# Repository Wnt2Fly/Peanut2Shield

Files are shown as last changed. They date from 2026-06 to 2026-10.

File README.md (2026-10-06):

# Peanut2Shield — TiVo Remote BLE HID Translator

**Firmware v1.21** — see [CHANGELOG.md](CHANGELOG.md)

An ESP32-S3 firmware that bridges a **TiVo Stream 4K remote** to an **Nvidia Shield TV** over Bluetooth LE — no WiFi, no app, no cloud.

<a href="https://www.buymeacoffee.com/wnt2fly" target="_blank">Buy Me A Coffee</a>

    

**Topics:** `esp32` · `esp32-s3` · `ble` · `bluetooth-low-energy` · `hid` · `nimble` · `nvidia-shield` · `android-tv` · `tivo` · `tivo-remote` · `platformio` · `waveshare`

---

## What it does

```
TiVo Remote  ──BLE HID──►  ESP32-S3  ──BLE HID──►  Nvidia Shield TV
              (Central)   Translator   (Peripheral)
```

The ESP32-S3 simultaneously acts as:

- **BLE Central** — connects to the TiVo remote as a HID host and receives button reports
- **BLE Peripheral** — advertises as a HID keyboard + consumer control device to the Shield

When a button is pressed on the TiVo remote, the firmware translates it (if needed) and forwards it to the Shield in real time.  Shield and TiVo bond addresses are stored in **NVS**; BLE keys persist across reboot when NimBLE bonding is enabled. After a normal reset or power cycle, the bridge **reconnects to both devices automatically** — Shield first (while advertising), then TiVo — and returns to **steady green** when both links are up.

**Updating firmware:** easiest is the [prebuilt file from your browser](#flash-from-your-browser-no-install) — no software to install. Developers can use [PlatformIO](#building-from-source-platformio) (`pio run --target upload`). The first boot after flashing a **new version** clears pairing — re-pair the Shield and TiVo remote.

---

## Hardware

| Part | Detail |
|---|---|
| MCU | [Waveshare ESP32-S3-Zero](https://www.waveshare.com/esp32-s3-zero.htm) (chip **ESP32-S3FH4R2** — 4 MB flash, **2 MB PSRAM required**) |
| LED | WS2812 RGB on GPIO 21 — colour-coded by connection state (see LED patterns below) |
| Boot button | GPIO 0 — short presses to manage bonds (see [Reset / forget bonds](#reset--forget-bonds)) |
| Power | USB-C — wall USB adapter preferred (see [Power](#power); avoid Shield USB data cable) |

---

## Power

The bridge must remain powered for BLE to work — it has no battery.

**Recommended:** a dedicated **wall USB adapter** (or always-on powered hub / TV USB that stays live in standby) behind the TV. Power-only sources are the most reliable.

### Do not power from the Shield USB port (recommended)

Earlier docs suggested the Shield’s USB port as an option. **Avoid that for day-to-day use.**

The Waveshare ESP32-S3-Zero exposes **USB Serial/JTAG** on its USB-C jack. The Nvidia Shield is a USB **host**: it often **enumerates** that serial device but never opens it. Firmware debug writes can then **stall**, the LED freezes (commonly **solid purple**), and BLE stops making progress — even though pairing was fine for days on wall power.

The Shield also has no practical setting to “ignore COM / USB serial gadgets” for this device.

| Power source | Notes |
|---|---|
| **Wall USB adapter** | Best — power only; no host grabbing USB serial |
| Powered hub / always-on TV USB | Good if it stays powered in standby |
| **Shield USB** | Not recommended — sleep/cut power *and* USB-serial hang risk |
| PC USB (no serial monitor) | Same hang risk as Shield USB; opening a COM monitor can unblock it |

**If you must use Shield USB anyway:** use a **charge-only** (power-only) USB cable or adapter that does **not** connect the data lines (D+/D−). That stops the Shield from talking USB serial to the board while still supplying 5 V. A normal data cable to the Shield is what triggers the hang.

**TiVo remote feels sluggish or “buffered”** (press OK, long pause, then action): the ESP32 is often under-powered or on a weak cable, not a pairing bug:

- Prefer a short, decent **wall-adapter** cable.
- Thin phone-charge cables and long runs are a common cause of lag.
- If you previously used Shield USB-A → USB-C for power, move to a wall adapter first before chasing firmware.

---

## LED patterns

**Read the pattern, not just the colour** — the blink timing tells you what to do next.

| Colour | Pattern | Meaning |
|---|---|---|
| Yellow | Steady | Boot — BLE stack initialising (~1–2 s after reset). |
| Purple | Slow blink (500 ms on/off) | **Pair / wait for Shield** — advertising, or Shield connected and finishing setup |
| Purple | **Solid** (not blinking) | **Stuck** — often USB host hang (Shield USB or PC USB with no monitor). Use wall power; see [Troubleshooting](#troubleshooting). |
| Deep orange | Double-flash … pause … repeat | **Pair the TiVo remote** — Shield ready, scanning for TiVo |
| Green | 3 quick flashes (once), then **steady on** (half brightness) | Both devices ready — stays green while paired |
| White | Single 80 ms flash | Button press forwarded to Shield; also a tick on each BOOT press |
| Purple | 3 quick flashes (once) → slow blink | Shield bond cleared (BOOT **3** presses / serial `s`) — pair from Shield |
| Deep orange | 3 quick flashes (once) → double-flash | TiVo bond cleared (BOOT **4** presses / serial `t`) — pair the remote |
| Red → green | 3 red flashes, 3 green flashes → purple slow blink | Factory reset (BOOT **5** presses / serial `f`) |
| Red | Slow blink (400 ms on/off) | **Wrong hardware** — no PSRAM detected; needs genuine Waveshare FH4R2 board |

> **Stuck on yellow?** Steady yellow for more than ~5 s usually means a **crash reboot loop** (BLE failed to start), not pairing mode.  
> **Stuck on solid purple?** Firmware hung after start (often Shield/PC USB serial) — use a **wall adapter**, not Shield USB. See [Troubleshooting](#troubleshooting).

> **Note:** Earlier firmware used the wrong WS2812 channel order (`NEO_GRB`), which made the purple slow-blink state look **cyan** on the Waveshare ESP32-S3-Zero. Reflash if colours still look swapped (e.g. cyan when you expect purple).

---

## Reset / forget bonds

### Serial commands (USB monitor)

Type a letter + Enter:

| Key | Action |
|-----|---|
| **t** | Forget **TiVo** only |
| **s** | Forget **Shield** only |
| **f** | **Factory reset** |
| **i** | Status |
| **h** | Help |

### BOOT button (short presses)

Press **BOOT** several times, then wait ~1 second (no more presses):

| Presses | Action |
|---|---|
| **3** | Forget **Shield** |
| **4** | Forget **TiVo** |
| **5** | **Factory reset** |

(1–2 presses do nothing.) Serial commands still work the same.

The reset itself takes well under a second. After the confirmation flashes the LED goes straight to the right pairing pattern — **no extra BOOT press is needed**:

- **3 presses** → 3 purple flashes → purple slow blink → pair from Shield **Settings → Remote & Accessories**.
- **4 presses** → 3 orange flashes → orange double-flash → put the TiVo remote in pairing mode. The Shield stays paired.
- **5 presses** → red, then green flashes → purple slow blink → pair Shield, then orange → pair TiVo, then green.

---

## Default key translation table

| TiVo button | Usage code | Forwarded as |
|---|---|---|
| TiVo | `0x003D` | Keyboard F4 |
| Live TV | `0x003E` | Keyboard F7 |
| Guide | `0x008D` | Keyboard F8 |
| Info | `0x0209` | Keyboard F9 |
| Skip | `0xCE00` | Keyboard F10 |
| Netflix | `0x01C8` | Keyboard F11 |
| Home | `0x0223` | Keyboard Home |
| Back | `0x0224` | Keyboard ESC (Android Back when [long-press](#long-press-tivimate-etc) is on) |
| OK / Select | `0x0041` | Consumer pass-through |
| Power | `0x0030` | **Ignored over BLE by default** (`CFG_IGNORE_TIVO_POWER_BLE=1`) — use TiVo IR Power; set to `0` in `config.h` to forward to Shield |
| Vol+ / Vol− / Mute | `0x00E9` / `0x00EA` / `0x00E2` | **Ignored over BLE by default** (`CFG_IGNORE_TIVO_VOLUME_BLE=1`) — use TiVo IR volume; set to `0` in `config.h` to forward to Shield |
| Navigation (▲▼◀▶) | `0x0042`–`0x0045` | Consumer pass-through; relaxed dedup (see below) |
| All other buttons | — | Consumer pass-through |

Keyboard-translated buttons get a forced **30 ms key-up pulse** so the Shield doesn't auto-repeat them.  Navigation keys skip the bounce guard and release immediately on all-zero idle reports from the TiVo's dual consumer characteristics, so directional repeat works naturally.  Identical-report hold dedup still applies to all keys.

To launch apps or change what a button does on the Shield, use **[Button Mapper](#custom-button-mapping-shield-side)** (recommended).  To change what the bridge sends before it reaches the Shield, edit `CFG_DEFAULT_KEYMAP` in `src/config.h` and reflash.

### Long-press (TiviMate, etc.)

By default every press reaches the Shield as a **short tap**, even if you hold the button — so long-press actions (e.g. TiviMate: hold **Back** in the guide to jump back to full screen, hold **OK** for "Play in external player" / "Add to favorites") don't fire.

To enable long-press, flash the **`longpress`** prebuilt file (see [Flash from your browser](#flash-from-your-browser-no-install)). If you build from source, set this in `src/config.h` instead and reflash:

```c
#define CFG_LONG_PRESS  1
```

With it on, buttons stay held on the Shield for as long as you hold them on the remote (up to 3 seconds), and **Back** is sent as a real Android Back key instead of Esc. F-keys and Home still send a short tap (Button Mapper single-tap mappings are unaffected). Leave it at `0` if you don't use long-press — behaviour is then identical to earlier versions.

**Power**, **Volume**, and **Mute** are ignored over BLE by default so they do not fight the TiVo remote’s IR (or CEC). See **[Power & volume via TiVo remote IR](#power--volume-via-tivo-remote-ir)** below. For **Input** or other IR-only keys, program IR on the remote the same way.

---

## Power & volume via TiVo remote IR

**Power, Vol+, Vol−, and Mute over BLE are ignored by default** (`CFG_IGNORE_TIVO_POWER_BLE=1` and `CFG_IGNORE_TIVO_VOLUME_BLE=1` in `config.h`). The TiVo remote still emits those keys on BLE, but Peanut2Shield does **not** forward them to the Shield — that was sleeping/waking the Shield (Power) or double-adjusting volume with IR/CEC. Program the remote’s **IR Power** and **IR Volume/Mute** for the TV or amp; navigation and app keys still go over BLE.

| Flag in `config.h` | Default | Effect when `1` |
|---|---|---|
| `CFG_IGNORE_TIVO_POWER_BLE` | `1` | Do not forward Power (`0x0030`) over BLE |
| `CFG_IGNORE_TIVO_VOLUME_BLE` | `1` | Do not forward Vol+ / Vol− / Mute (`0x00E9` / `0x00EA` / `0x00E2`) over BLE |

Set either flag to `0` and reflash only if you want that key group over BLE again.

The Stream 4K remote is not using the Shield’s IR blaster — it sends infrared from the remote body toward your TV or soundbar.

### Shield TV (CEC)

On the Shield, leave **main HDMI-CEC enabled**, but **turn off CEC for volume and power** so the Shield does not fight IR for those keys.

Exact menu names vary by Shield model and Android TV version; look under **Settings → Device Preferences → Display & Sound** (HDMI-CEC).

### TiVo remote — program IR codes

Use TiVo’s manual code entry so **Power**, **Volume**, **Mute**, **Input**, and **AV / amplifier** keys on the remote control your TV or soundbar over **IR**. Navigation and app keys still go to the Shield through Peanut2Shield over BLE.

**Code list (in this repo):** [`tivo_programming_codes.txt`](tivo_programming_codes.txt) — setup codes by brand plus step-by-step programming for each key group (TV power, input, volume/mute, audio amplifiers, etc.). Use this when CEC does not handle power, volume, input, or AV reliably.

**Also online:** [TiVoCommunity — disable automatic remote programming](https://www.tivocommunity.com/?threads/heres-how-to-disable-tivos-automatic-remote-programming.577390/) (same idea; the `.txt` file is easier to search offline on a USB stick copy of the project).

**Quick example (TV power — see the file for Input / Vol / Mute):**

1. Find your TV brand in `tivo_programming_codes.txt` and note the **first code** listed.
2. Hold **TiVo + TV Power** for **3 seconds** until the activity LED stays on.
3. Enter the code with the number keys; the LED blinks three times and turns off.
4. Point at the TV and press **TV Power** to test.
5. If it fails, repeat with the **next code** for that brand until Power (and, per the guide, Input / Vol / Mute) work.

This is independent of Peanut2Shield BLE pairing; program IR after OK, Home, and app keys work over the bridge.

---

## Custom button mapping (Shield side)

Peanut2Shield turns several TiVo buttons into **keyboard F-keys** (see table above).  On the Shield, map those keys to any app with **[Button Mapper](https://play.google.com/store/apps/details?id=flar2.homebutton)** by flar2 (free, Play Store) — no root, no firmware reflash.

### Setup Button Mapper (one time)

1. On the Shield: install **Button Mapper** from the Play Store.
2. Open it and allow **Accessibility** when prompted: **Settings → Device Preferences → Accessibility → Button Mapper → ON**.
3. In Button Mapper, choose **Add buttons**.
4. Press the TiVo button you want to remap (via Peanut2Shield).  It should appear as a key (e.g. **F7** for Live TV).
5. Turn **Customize** on, set **Single tap** (or **Long press**, if you prefer) to **Applications**, and pick the app.
6. If the key is not detected or the old action still fires, open **Troubleshooting** in Button Mapper and try **Alternate button handling**.

### Example: Live TV → YouTube TV

The bridge sends **F7** when you press **Live TV** on the TiVo remote.

1. **Add buttons** → press **Live TV** on the TiVo remote → select **F7**.
2. **Customize → Single tap → Applications → YouTube TV**.
3. Press **Live TV** again — YouTube TV should open.

Same idea for other mapped buttons:

| TiVo button | Key sent to Shield | Example remap |
|---|---|---|
| TiVo | F4 | Your DVR app |
| Live TV | F7 | YouTube TV |
| Guide | F8 | Plex |
| Info | F9 | Any app |
| Skip | F10 | Any app |
| Netflix | F11 | Keep Netflix or map to another app |

Consumer pass-through buttons (OK, nav, etc.) are not F-keys — remap them in Button Mapper the same way if the app detects the consumer key, or change the firmware default in `config.h`. Volume/Mute/Power are not forwarded over BLE by default (IR); see above.

### Firmware-level remapping (advanced)

Edit `CFG_DEFAULT_KEYMAP` in `src/config.h` if you need the bridge to emit a different key or consumer code, then reflash.  NVS custom remap storage exists in code but has no runtime UI yet; factory reset clears stored custom entries.

---

## First-time pairing

After reset, the normal sequence is: **steady yellow** (brief, while BLE starts) → **slow blink** (500 ms on / 500 ms off) → **double-flash** → **3 quick green flashes** → **steady green**.

If you only see a **slow blink** and never noticed yellow, that is fine — slow blink means you are on step 2.

### 1 — Power on

Press **RESET** (or power on). The LED may show **steady yellow** briefly while the BLE stack starts. When it settles into a **slow blink** (lit half a second, dark half a second), the bridge is advertising and waiting for the Shield.

### 2 — Pair the Shield  ← do this when you see slow blink

1. On the Shield: **Settings → Remote & Accessories → Add Accessory**
2. Select **Peanut2Shield** — it pairs automatically (no PIN)
3. Keep **slow blink** while the Shield finishes setup (CCCD negotiation) — do not pair the TiVo yet
4. LED stays **purple** while the Shield finishes setup, then switches to **deep orange double-flash** — pair the TiVo remote now

### 3 — Pair the TiVo remote  ← do this when you see deep orange double-flash

The bridge is already scanning. Put the **TiVo Stream 4K** remote in BLE pairing mode:

1. **Clear / reset the remote** (if it was paired elsewhere or acts stuck):
   - Hold **Power + TiVo** until the activity light turns **red**
   - Press **Volume Down** three times → light stays **solid red**
   - Press the **TiVo** button
2. **Enter pairing mode** — press **any button** on the remote (activity light should show it is searching)
3. Peanut2Shield connects automatically when it sees `TiVo Remote` advertising HID (`0x1812`)
4. Keep the link up **5 seconds** — LED stays deep orange briefly, then **3 green flashes** and **steady green**

### Re-pairing

| What to re-pair | Method | LED after |
|---|---|---|
| Both | Serial **f**, or BOOT **5** presses | Red flashes → green flashes → purple slow blink |
| TiVo remote | Serial **t**, or BOOT **4** presses | Orange quick flashes → orange double-flash; reset remote then any button |
| Shield | Serial **s**, or BOOT **3** presses | Purple quick flashes → purple slow blink |

### After reboot

If both devices were paired before, you do **not** need to open Shield settings or put the TiVo remote in pairing mode again.

Power from a **wall USB adapter** (not Shield USB with a data cable). See [Power](#power).

1. Power on or press **RESET** — brief **yellow**, then **purple slow blink** while the Shield reconnects (the bridge waits up to ~30 s for a sleeping Shield).
2. TiVo reconnects automatically once the Shield is linked (or after the 30 s window if the Shield stays asleep).
3. **Steady green** = both ready; white flash on button press = keys reaching the Shield.

**Power outage / Shield wake:** the bridge should come back to steady green on its own (fixed in v1.18 and v1.20). If one is still on **orange double-flash** after a minute while the remote works, press **RESET** once.

If the LED is **solid purple** (not blinking), the board is hung on USB serial — move to wall power or a charge-only cable.

If you see **white flashes** but the Shield does not respond, the TiVo link is up but the Shield is not — wait a few seconds, wake the Shield, or press **BOOT 3 times** to re-pair the Shield side only.

**Shield powered off while TiVo stays paired:** the bridge keeps the TiVo link when possible and uses **slow advertising** so re-advertising for the Shield does not starve the remote. When the Shield comes back, the bridge reconnects the TiVo remote once using the saved bond (a brief orange blip) to refresh its button channels — no re-pair needed. If the remote went to sleep, press any button once to wake it.

---

## 3D-printed case

A snap-together enclosure designed specifically for the **Waveshare ESP32-S3-Zero** is included in the `case/` folder.

### Parts

| File | Description | Suggested material |
|---|---|---|
| `case/base.stl` | Bottom tray — holds the board, USB-C side opening | Any PLA/PETG |
| `case/top.stl` | Snap-on lid — engraved button labels, LED hole | Any PLA/PETG |
| `case/led.stl` | Clear LED light-pipe insert (captured in lid) | Clear/transparent PETG or resin |

### Printing notes

- Print `base.stl` and `top.stl` at **0.2 mm layer height**, 3 perimeters, 15% infill — no supports needed
- Print `led.stl` in **clear filament** at 0.1 mm layers for best light transmission; orient flat-side down
- The lid snaps onto the tray — no hardware required
- The light-pipe press-fits into the lid from below and is retained by a small flange

### Modifying the design

The source file `case/waveshare esp32-s3-zero_case.scad` is a parametric [OpenSCAD](https://openscad.org/) model (v32).  Open it in OpenSCAD and use **Render → Export as STL** with the export variable set to the part you want (`top`, `base`, or `led_insert`).

---

## Building & flashing

Two ways to put firmware on the board. Both need a USB-C **data** cable (charge-only cables won't work).

### Flash from your browser (no install)

Prebuilt files are in the [`firmware/`](firmware/) folder. Each is a complete image in a single file:

| File | Use it if |
|---|---|
| `Peanut2Shield-v1.21-standard.bin` | Normal use — every press is a short tap (same as earlier versions) |
| `Peanut2Shield-v1.21-longpress.bin` | You use long-press in apps like TiviMate (hold Back / hold OK) — see [Long-press](#long-press-tivimate-etc) |

Works on **Windows, Mac, or Linux** with **Chrome** or **Edge** (Safari and Firefox can't talk to USB serial devices):

1. Download the `.bin` file you want from [`firmware/`](firmware/).
2. Plug the Peanut2Shield into the computer with a USB-C **data** cable.
3. Open [espressif.github.io/esptool-js](https://espressif.github.io/esptool-js/).
4. Click **Connect** and pick the board's port (Windows: `COMxx` / "USB JTAG/serial debug unit"; Mac: `usbmodem…`).
5. Under **Program**, set **Flash Address** to `0x0`, choose the `.bin` file, and click **Program**.
6. When it says it's done, unplug the board, plug it into its wall adapter, and press **RESET**.
7. Pairing is cleared — pair the Shield first (purple slow blink), then the TiVo remote (orange double-flash). See [First-time pairing](#first-time-pairing).

If **Connect** doesn't find the board: hold the **BOOT** button while plugging the board in, release it, then click **Connect** again.

From a terminal instead of the browser: `esptool.py --chip esp32s3 write_flash 0x0 Peanut2Shield-v1.21-standard.bin`

> Flashing a prebuilt file always clears pairing, even if it's the same version — the image overwrites the area where pairing is stored.

### Building from source (PlatformIO)

Firmware is built and flashed with **[PlatformIO](https://platformio.org/)** (CLI or VS Code extension).

After any flash, press the board **RESET** button once. The ESP32-S3-Zero uses native USB-CDC, so upload does not always auto-reboot the chip.

**Build:**

```bash
pio run
```

**Flash** (close any serial monitor first — the COM port can only be used by one program):

```bash
pio run --target upload
```

**Recover a crash-looping board** (full erase + upload — clears bad NVS):

```bash
# Windows helper:
flash-recover.bat COM20

# Or manually:
pio run -t erase --upload-port COM20
pio run -t upload --upload-port COM20
```

**Monitor** (115200 baud — useful while pairing):

```bash
pio device monitor -p COM20 -b 115200
```

Good boot on serial:

```
=== TiVo BLE HID Translator v1.21 ready ===
[BOOT] flash=4096 KB  PSRAM=2048 KB  heap=...
[HID] Peripheral ready — advertising as 'Peanut2Shield'.
```

**Rebuild the prebuilt files** in `firmware/` after changing the code or bumping `CFG_FIRMWARE_VERSION` (Windows PowerShell):

```powershell
powershell -ExecutionPolicy Bypass -File make-release.ps1
```

It builds the long-press and standard variants and writes `firmware/Peanut2Shield-<version>-longpress.bin` and `-standard.bin`, replacing the old ones. It builds standard last, so a following `pio run --target upload` flashes the default.

On PC USB power, expect brief **yellow**, then **purple slow blink** if nothing is paired yet. Opening the serial monitor can change behaviour: with no reader, USB serial writes may **block** and freeze the LED (solid purple/yellow). Prefer wall power for normal TV use.

---

## Troubleshooting

### LED stuck on yellow or solid purple

| Symptom | Likely cause | Fix |
|---|---|-----|
| Yellow **~1–2 s**, then purple **blink** | Normal boot | Pair Shield if new; ignore if already green behind TV |
| Yellow **forever** or keeps restarting | BLE crash loop (`ESP_ERR_NO_MEM` on serial) | **`flash-recover.bat COM<N>`** or `pio run -t erase` then upload |
| **Solid purple** (not blinking) after power cycle | USB host enumerated serial but nothing reads it (Shield USB / PC without monitor) | Power from a **wall USB adapter**; avoid Shield USB. Optional: charge-only cable if you must use Shield power |
| Resets or forgets bonds by itself | BOOT button stuck or case pressing it | Check the case isn’t pressing BOOT |
| **Red** slow blink | No PSRAM on chip | Wrong board — need **Waveshare ESP32-S3-Zero (FH4R2)** with 2 MB PSRAM |

### Serial shows `ESP_ERR_NO_MEM` or `Config struct mismatch`

Usually **stale NVS** after a partial flash, or PSRAM not enabled.

Fix:

1. Close the serial monitor (Ctrl+C).
2. **`flash-recover.bat COM<N>`** (or `pio run -t erase` then upload).
3. Press **RESET** once; expect **purple slow blink** within a few seconds. Re-pair Shield and TiVo.

The firmware also clears NVS on first boot after any firmware version change (re-pair once).

### Upload / flash errors

| Error | Fix |
|---|-----|
| `Cannot configure port` / port missing | Serial monitor still open — close it first |
| `No serial data received` | Unplug/replug USB, press RESET, try another cable/port |
| Upload OK but still yellow | Run **erase** then upload again |

### White flashes but Shield ignores buttons

TiVo is connected but Shield is not. Wait up to ~30 s after reboot, wake the Shield, or press **BOOT 3 times** to re-pair Shield only.

### Some buttons (e.g. Back) stop working, no white flash

The TiVo link is up but one of its report channels stopped delivering. v1.17+ repairs this automatically (reconnects the remote with its saved bond after Shield events, and re-subscribes every 5 minutes). If it still happens, press **BOOT 4 times** and re-pair that remote, and check its batteries.

### Orange double-flash, but the remote still works

The bridge lost track of a TiVo connection that was still alive. Fixed for power outages in v1.18 and for Shield sleep/wake in v1.20. On older firmware, press **RESET** once.

---

## Project structure

```
├── CHANGELOG.md                # Version history
├── LICENSE                     # MIT license
├── flash-recover.bat           # Windows: erase + upload (recover crash loop)
├── make-release.ps1            # Rebuild the prebuilt images in firmware/
├── firmware/
│   ├── Peanut2Shield-v1.21-standard.bin    # Prebuilt, flash at 0x0 (browser)
│   └── Peanut2Shield-v1.21-longpress.bin   # Same, with long-press on
├── sdkconfig.defaults          # PSRAM / BLE memory settings for ESP32-S3-Zero
├── tivo_programming_codes.txt  # TiVo IR codes (power, vol, input, AV) if CEC fails
├── platformio.ini              # Board, platform, library dependencies
├── case/
│   ├── base.stl                # Bottom tray (3D print)
│   ├── top.stl                 # Snap-on lid (3D print)
│   ├── led.stl                 # Clear LED light-pipe insert (3D print)
│   └── waveshare esp32-s3-zero_case.scad   # Parametric OpenSCAD source
└── src/
    ├── config.h                # All compile-time constants (edit here to customise)
    ├── Peanut2Shield.cpp       # Main: BLE central, notify callback, LED engine, button handler
    ├── hid_peripheral.cpp      # BLE peripheral: HID GATT server, report sending
    ├── hid_peripheral.h
    ├── keymap.cpp              # Translation table, NVS persistence
    ├── keymap.h
    ├── boot_early.cpp          # Silence USB serial hang before setup
    ├── devlog.h / devlog.cpp   # Serial logging only when a host is connected
    └── …
```

---

## Dependencies

| Library | Version |
|---|---|
| [h2zero/NimBLE-Arduino](https://github.com/h2zero/NimBLE-Arduino) | `^1.4.3` |
| [adafruit/Adafruit NeoPixel](https://github.com/adafruit/Adafruit_NeoPixel) | `^1.12.0` |
| Preferences | bundled with ESP32 Arduino core |

Platform: `espressif32`, framework: `arduino`, board: `esp32-s3-devkitc-1` with `board_build.flash_size = 4MB`, `board_build.arduino.memory_type = qio_qspi`, and `sdkconfig.defaults` for quad PSRAM. Firmware version: `CFG_FIRMWARE_VERSION` in `src/config.h`.

---

## Technical notes

- **PSRAM required** — Dual BLE (central + peripheral) needs the **2 MB PSRAM** on the ESP32-S3FH4R2. At boot the firmware logs `[BOOT] PSRAM=… KB`; values under ~512 KB halt with a red blink.
- **Dual BLE roles** — NimBLE-Arduino runs Central and Peripheral simultaneously on the single radio via time-slicing.
- **Connection intervals** — Shield link targets 7.5–15 ms (`CFG_CONN_*`, 510 ms supervision); the update fires 1 s after CCCD write to avoid disrupting Android's service discovery. TiVo link uses 15–30 ms with a 4 s supervision timeout (`CFG_TIVO_CONN_*`) so the remote doesn't drop.
- **Key-release pulse** — Keyboard-translated buttons get a forced 30 ms key-up (`CFG_KB_PULSE_MS`) so the Shield doesn't auto-repeat them on hold.
- **Bounce guard** — `CFG_BOUNCE_GUARD_ACTION_MS` suppresses the same usage code arriving too soon after key-up (currently **0 ms**, disabled).  Increase if action buttons double-fire.  Nav keys always skip it.
- **Nav key fast-path** — Navigation keys (0x0042–0x0045) skip the bounce guard and release immediately on all-zero idle reports instead of waiting for the 50 ms all-zero guard (`CFG_ALL_ZERO_GUARD_MS`).  Identical-report hold dedup still applies to all keys.
- **Power / volume over BLE** — By default Power (`CFG_IGNORE_TIVO_POWER_BLE=1`) and Vol+/Vol−/Mute (`CFG_IGNORE_TIVO_VOLUME_BLE=1`) are **not** forwarded to the Shield (use TiVo IR). Set either flag to `0` to restore BLE pass-through for that group. If Power is forwarded, it uses a forced 30 ms release pulse.
- **NVS namespaces** — `tivo` (address + `trusted` after 5 s link), `shield` (address after CCCD), `keymap` (custom remaps — storage only; no runtime UI yet). NimBLE bond keys use `CONFIG_BT_NIMBLE_NVS_PERSIST` in `platformio.ini`.
- **Boot reconnect** — On power-up with both bonds stored, TiVo central reconnect waits for the Shield to link, or up to `CFG_SHIELD_RECONNECT_BOOT_MS` (30 s) if it stays asleep. Advertising keeps running (slow intervals) while the Shield is not linked so it can always find the bridge.
- **TiVo link refresh** — After a mid-session Shield drop and reconnect, the TiVo link is soft-refreshed: disconnected and reconnected with the saved bond (`CFG_TIVO_SOFT_REFRESH_*`, 2 min cooldown). Not done on cold boot / power restore. While linked, all TiVo report CCCDs are re-subscribed every `CFG_TIVO_RESUBSCRIBE_MS` (5 min); fewer than `CFG_TIVO_MIN_SUBSCRIBED_REPORTS` (2) triggers a soft refresh.
- **Shield drop while TiVo linked** — After a mid-session Shield disconnect, peripheral advertising uses slow intervals (`CFG_ADV_SLOW_MIN_INTERVAL` / `CFG_ADV_SLOW_MAX_INTERVAL`, 100–300 ms) while the TiVo central link is still up, so fast 20–40 ms re-advertise does not starve the remote. When TiVo also drops, advertising returns to the fast pairing intervals.
- **LED** — Non-blocking state machine driven by `ledTick()` in `loop()`. Priority: Activity (white) > base pattern. Purple slow blink = Shield pairing; deep orange double-flash = TiVo pairing; green = ready. Global brightness controlled by `CFG_LED_BRIGHTNESS` in `config.h`.
- **Shield dropout debug** — `CFG_SHIELD_DEBUG=1` in `config.h` logs `[HID-DBG]` on connect/disconnect (uptime, conn interval, supervision timeout, advertising state), TiVo central pause/resume, fast-params timing, 30 s heartbeat, and ESP reset reason at boot. Set `CFG_SHIELD_DEBUG` to `0` to silence.

---

## License

[MIT](LICENSE) — do whatever you like with it.

---

## Support

If this project saved you a broken remote or a pile of HDMI switches, consider **[buying me a coffee](https://www.buymeacoffee.com/wnt2fly)** — same link as my [F1-Info-display-Enhanced](https://github.com/Wnt2Fly/F1-Info-display-Enhanced) project.

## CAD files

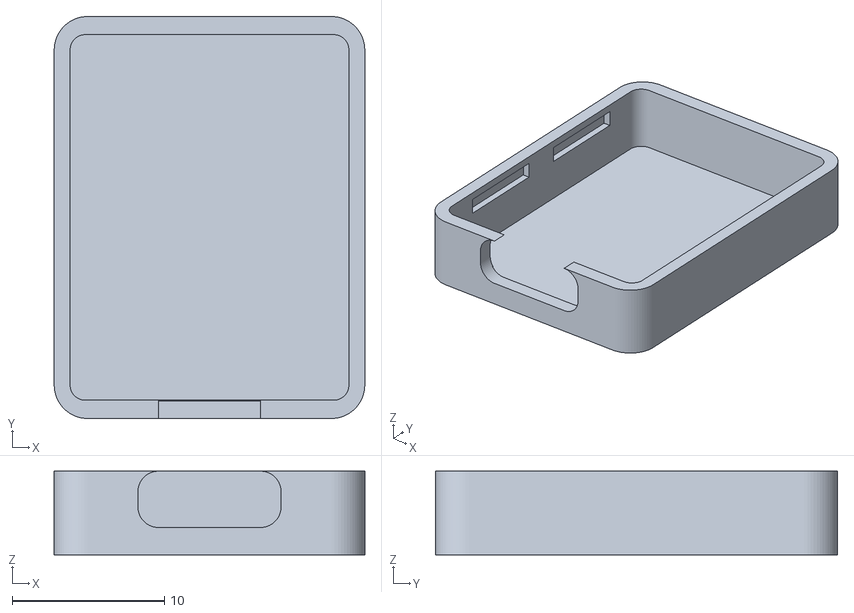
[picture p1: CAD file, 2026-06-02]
case/base.stl
20.4 x 26.4 x 5.50

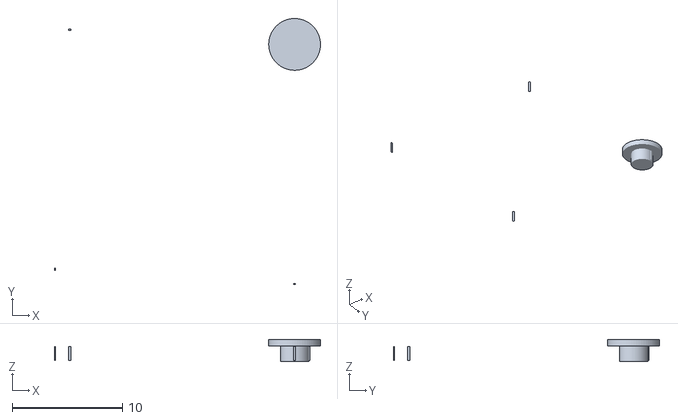
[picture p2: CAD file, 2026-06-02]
case/led.stl
24.1 x 24.1 x 2.03

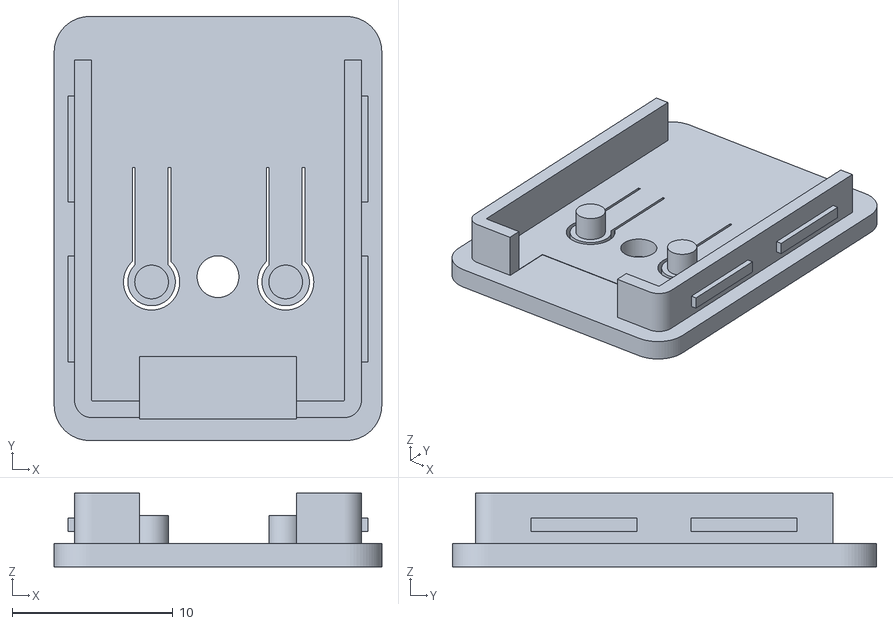
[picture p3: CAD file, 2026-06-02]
case/top.stl
20.4 x 26.4 x 4.60

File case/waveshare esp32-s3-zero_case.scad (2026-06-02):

// Waveshare ESP32-S3-Zero case with two button actuators
// v32: tightens the button-to-cutout gaps and adds LED light-pipe glue/retention features.
// v31: removes the raised edge/stiffening rib on the top cap, widens the button pads, and changes the switch contact nubs from cones to flat cylinders.
// v30: fixes snap receiver pockets so they are derived from the same tab coordinates and correct installed Z height.
// v29: sets measured lid-to-button gap to 1.80 mm and derives the top button nub height from it.
// v28: removes board support rails, sets USB opening bottom to 1.80 mm, interior height to 5.00 mm, and lid rim depth to 3.25 mm.
// v27: removes the rear/back segment of the top cap underside rim.
// v26: floor_h=0.50, rail_h=0.50, USB slot z0=2.30, and cap rim calculated to slightly touch the 1.6 mm PCB.
// v24: USB relief is localized to the connector body only, not a full-height pocket around the opening.
// v23: cleans the USB/front wall area and adds a matching USB clearance notch in the snap-on top cap.
// v22: adds engraved button designations on the outside/top face of the cap.
// v21: LED window reworked as a captured separate clear light-pipe part for slicers.
// - Default all view shows bottom tray, top lid/cap, and the clear LED pipe installed in the lid.
// - Export top/lid/cap produces the actual snap-on clamshell lid with a clean LED hole.
// - Export led_insert produces only the clear LED pipe, aligned to the top lid origin.
// - The LED pipe has a small underside flange so it is retained and slicers stop confusing it with a loose center circle.
// Button islands are full top-plate thickness; only the press nubs project from the inside face.
// Buttons, LED window/clear insert, and button contact nubs are on the TOP piece.
// Bottom is a closed tray for the board, rails, USB-C side opening, and snap receivers.
// v10 base was fit-checked against the uploaded ESP32-S3-Zero STEP model.
// Board/button coordinates below are extracted from the STEP CARTESIAN_POINT data, not eyeballed from the drawing.
// Recreated from STL measurements (not a mesh import).
// Coordinate system: base lower-left-front corner = [0,0,0]. Units: mm.

$fn = 64;

// Export selector:
//   "all"       = bottom tray + TOP LID/CAP + clear LED insert laid out as separate printable bodies
//   "base"      = base only
//   "led_insert"= clear LED plug only, at the SAME origin as the top so it can be imported as an aligned part
//   "led_insert_layout" = clear LED plug laid out next to the cap for visual checking
//   "top_with_led_preview" = top with LED insert shown in-place for checking only, not for multi-material export
//   "top"/"lid"/"cap" = snap-on clamshell top lid only
//   "lid_split" = split two-piece lid laid out together
//   "lid_left"  = left-side lid half
//   "lid_right" = right-side lid half
//   "lid_front" = legacy alias for left-side lid half
//   "lid_back"  = legacy alias for right-side lid half
// This makes it easier to import the LED insert as a separate part and assign clear PLA.
export_part = "base";   // default: bottom + TOP LID + separate LED insert laid out side-by-side

// ---------------- measured outer dimensions ----------------
base_w = 20.40;
base_d = 26.40;
floor_h = 0.50;      // v26/v28: thin closed bottom floor
interior_h = 5.00;   // v28: full inside height above floor
base_h = floor_h + interior_h;  // outside height = bottom floor + interior = 5.50 mm
corner_r = 2.20;
wall_t  = 1.20;

// Waveshare ESP32-S3-Zero board outline from drawing.
board_w = 18.01;          // STEP board max X ~18.0087 mm
board_d = 23.51;          // STEP board max Y ~23.5086 mm
board_corner_r = 1.00;
board_clear_x = 0.30;      // FDM clearance; v8 had exactly 18.00 mm and would be too tight
board_clear_y = 0.50;
board_x0 = (base_w - board_w) / 2;
board_y0 = 1.20;           // board USB edge sits against the inside of the connector wall

// Interior tray opening. Slightly widened vs the measured STL so the 18.00 mm board actually fits.
inner_x0 = board_x0 - board_clear_x/2;
inner_x1 = board_x0 + board_w + board_clear_x/2;
inner_y0 = board_y0;
inner_y1 = board_y0 + board_d + board_clear_y;

// Raised internal side rails measured at z=1.2..2.95
rail_w = 1.50;
rail_h = 0.00;       // v28: rails removed; board sits on the floor
rail_z = floor_h;
rail_y0 = 1.20;
rail_y1 = 25.20;
rail_inner_left_x0  = inner_x0;
rail_inner_left_x1  = inner_x0 + rail_w;
rail_inner_right_x0 = inner_x1 - rail_w;
rail_inner_right_x1 = inner_x1;
rail_r = 0.45;

// USB-C opening.
// USB-C receptacle shell is roughly 8.4 x 2.6 mm; these are printable clearance dimensions.
// The original STL connector access was on the front-notch end, not the opposite wall.
// Toggle usb_on_back_wall if your slicer/model coordinate view shows it on the wrong edge.
// USB-C connector mouth/plug clearance. USB-C receptacle shell is about 8.4 x 2.6 mm;
// 9.4 x 3.7 gives sane FDM clearance without turning it into the old giant notch.
usb_c_open_w  = 9.40;
usb_c_open_h  = 3.70;
usb_c_open_r  = 1.35;
usb_c_center_x = board_x0 + board_w/2;
usb_c_open_x0 = usb_c_center_x - usb_c_open_w/2;
usb_c_open_z0 = 1.80;     // v28: USB-C opening bottom height
usb_on_back_wall = false;   // false = original notch/button end at y=0; true = opposite wall at y=base_d

// v24 USB cleanup / lid relief.
// Do NOT make a big full-height pocket around the whole USB opening.
// The only extra inside clearance is a localized pocket for the USB-C metal body
// where it projects back into the case over the PCB.
usb_inner_pocket = false;              // legacy v23 big bay; keep OFF
usb_body_pocket = true;                // localized connector-body relief only
usb_body_pocket_w = 8.90;              // USB-C receptacle body width; not cable shell width
usb_body_pocket_h = 3.10;              // local body height
usb_body_pocket_depth = 3.10;          // how far the connector body projects into the box
usb_body_pocket_z0 = floor_h + rail_h + 0.65; // bottom of relief: board support + approx PCB/top offset

// Matching clearance in the TOP cap/lid so it closes around the USB-C receptacle body.
// v25 IMPORTANT: this is NOT a through-cut in the visible top lid.
// It cuts only the underside plug/rim/skirt -- the part that inserts into the bottom box.
cap_usb_notch = true;
cap_usb_notch_w = usb_body_pocket_w + 0.90;
cap_usb_notch_depth = usb_body_pocket_depth + 0.70;
cap_usb_notch_extra_h = 0.30;
cap_usb_cut_visible_top = false;     // keep false: only notch the underside rim, not the top plate
cap_usb_notch_z_clear = 0.03;        // tiny overlap so CSG cleanly removes the rim material

// The old bottom pry relief overlapped visually with the USB area. Default off in v23.
bottom_pry_relief = false;

// Original STL had an open floor channel here. v6 closes the bottom/floor,
// leaving only the USB-C wall opening above.
front_cut_x0 = 5.70;
front_cut_x1 = 14.70;
front_cut_y1 = 7.99;

// Center LED window. The base still has a circular cutout, but v11 adds a matching
// separate insert object so this area can be assigned to clear PLA/transparent filament
// in the slicer. For a single-material print, set show_led_insert = false.
center_hole_x = 10.20;
center_hole_y = 10.20;
center_hole_r = 1.50;          // nominal LED location radius from original STL

// v21 LED lens/light-pipe parameters.
// The top lid gets a slightly oversized clean hole. The separate clear part has a
// smaller flush shaft plus a larger underside flange, like a tiny rivet/mushroom.
// This is more slicer-friendly than a same-radius cylinder touching the lid wall.
led_hole_r = 1.3;             // hole cut in the top lid
led_pipe_r = 1.50;             // v32: tighter fit in hole; still leaves ~0.08 mm radial clearance
led_pipe_h = 1.47;             // should be cap_top_h + tiny overlap; set after cap_top_h if you change cap_top_h
led_flange_r = 2.35;           // v32: larger hidden glue flange/washer
led_flange_h = 0.60;           // v32: taller flange gives more glue area
led_retention_ribs = true;     // v32: tiny ribs on clear pipe for glue/friction
led_retention_rib_count = 4;
led_retention_rib_w = 0.20;
led_retention_rib_out = 0.10;
led_insert_top_proud = 0.00;   // keep outside face flush; do not make proud unless you want a bump
show_led_insert = true;        // preview/layout only. Export top and led_insert separately for multi-material.
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

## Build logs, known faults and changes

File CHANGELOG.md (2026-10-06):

# Changelog

All notable firmware and documentation changes for Peanut2Shield.
The firmware version lives in `CFG_FIRMWARE_VERSION` in `src/config.h`.

> **Upgrading clears pairing once.** The first boot after flashing a *different* version erases NVS, so you re-pair the Shield and the TiVo remote one time. Re-flashing the *same* version with PlatformIO keeps pairing; flashing a prebuilt single-file image always clears it.

---

## v1.21 — 2026-10-06

### Fixed
- **Long-press mode: every tap acted like a hold.** A tap on OK opened TiviMate's side menu, a single Back gave the guide with a black picture, and Back sometimes did nothing. Key releases were sent from the main loop, so whenever the loop stalled the button stayed down on the Shield. Releases now run from their own timer and no longer depend on the main loop. This applies to both builds: the Esc/F-key/Home short taps now use the timer too.
- **LED freezing on solid white/purple and no longer flashing on button presses.** The Bluetooth callback and the main loop could both drive the LED at the same moment. Only the main loop writes to the LED now; button presses just request a flash.

### Added
- **Safety release in long-press mode** (`CFG_LONG_PRESS_MAX_HOLD_MS`, 3 s): a held key is always released on the Shield after 3 s, even if the remote's key-up is lost.

## v1.20 — 2026-10-06

### Added
- **Prebuilt firmware in the repo** (`firmware/`): `Peanut2Shield-v1.20-standard.bin` and `Peanut2Shield-v1.20-longpress.bin`. Each is a complete single-file image that flashes at address `0x0` from Chrome/Edge ([esptool-js](https://espressif.github.io/esptool-js/)) on Windows, Mac, or Linux — no PlatformIO needed.
- **`make-release.ps1`** rebuilds both images from source.
- **Optional long-press pass-through** (`CFG_LONG_PRESS`, **off by default**; the `longpress` image has it on). Buttons stay held on the Shield for as long as they are held on the remote, so apps like TiviMate see long-presses (long Back to jump back to full screen, long OK for "Play in external player" / "Add to favorites"). Back is sent as Android Back instead of Esc in this mode. F-keys and Home keep the short tap. With the default `0`, button behaviour is unchanged from v1.18. Can also be set at build time with `-DCFG_LONG_PRESS=1`.

### Fixed
- **Orange double-flash while the remote still works (after Shield sleep/wake).** A TiVo disconnect scheduled a reconnect for 3 s later, but the main loop also reconnected immediately. When the timer then fired, a second connection was started on top of the live one: the old link kept forwarding keys, while the bridge marked the TiVo "not ready" and retried every couple of seconds. Now:
  - the scheduled 3 s reconnect is the only reconnect path,
  - a reconnect is skipped if the TiVo is already connected (HID setup is re-run instead),
  - a disconnect from an old, replaced client no longer marks the current link not-ready.

## v1.18 — 2026-09-10

### Fixed
- **Stuck orange double-flash after a power outage.** When power returned, the Shield and TiVo reconnected at the same time and the v1.17 soft refresh tore down the TiVo link mid-recovery. The remote kept working but the LED stayed on orange double-flash until RESET. Soft refresh now runs only after the Shield drops **mid-session** and comes back — never on cold boot or power restoration.
- **Self-heal for a "connected but not ready" TiVo link.** If the TiVo is connected with a trusted bond but the ready flag was lost, HID setup re-runs automatically instead of waiting for a RESET.

## v1.17 — 2026-09-08

### Fixed
- **Back (and other keys) dropping out until re-pair.** The TiVo link could stay "connected" while one of its two HID report channels stopped delivering, so some keys never reached the bridge (no white flash). Re-pairing fixed it only temporarily.
  - **Soft refresh:** after the Shield drops and reconnects, the bridge disconnects and reconnects the TiVo remote using the **saved bond** — no forget, no pairing mode.
  - **Periodic re-subscribe:** every 5 minutes the bridge re-enables notifications on all TiVo report channels.
  - **Subscribe check:** if fewer than two report channels come up after connect, a soft refresh is scheduled automatically.
- New tuning constants in `config.h`: `CFG_TIVO_SOFT_REFRESH_COOLDOWN_MS`, `CFG_TIVO_SOFT_REFRESH_AFTER_SHIELD_MS`, `CFG_TIVO_RESUBSCRIBE_MS`, `CFG_TIVO_MIN_SUBSCRIBED_REPORTS`.

## v1.16 — 2026-08-14

### Fixed
- **Extra BOOT press needed after 3 or 4 presses.** The confirmation flashes were saved as the LED's base pattern, so they looped and blocked the normal pairing LED until another press. Confirmation flashes are now one-shot and the LED returns to the pairing pattern on its own.
- Forget-TiVo (4 presses / serial `t`) now confirms with **orange** flashes (was purple).

### Changed
- **Steady green "ready" LED is half as bright** (`CFG_LED_COLOR_READY` = `0, 128, 0`).

## v1.15 — 2026-08-14

### Fixed
- After the BOOT confirmation flashes, the LED returns to the base pattern instead of staying on the confirm animation.

## v1.14

### Fixed
- 3-press Shield forget no longer leaves the LED on a repeating purple double-flash; it shows a one-time confirm, then the normal pattern.

## v1.13

### Changed
- **BOOT button uses short presses** instead of hold timings: **3 = forget Shield, 4 = forget TiVo, 5 = factory reset** (wait ~1 s after the last press). Each press gives a brief white tick.

## v1.12

### Added
- Serial commands over the USB monitor: `t` forget TiVo, `s` forget Shield, `f` factory reset, `i` status, `h` help.

## v1.11 — 2026-08-04

### Fixed
- Serial monitor showed nothing: logging was gated on `(bool)Serial`, which often stays false on ESP32-S3 USB. Logs now print whenever `setup()` has finished.

## v1.10 — 2026-08-04

### Fixed
- **Purple blink → solid orange with no Shield resync after unplug/replug.** A TiVo reconnect paused advertising, so the Shield never found the bridge. Advertising now continues (slow intervals) while the Shield is not linked.
- A Shield address stored in NVS is no longer treated as "Shield ready" on cold boot.
- Boot wait for the Shield before starting TiVo work raised to 30 s (`CFG_SHIELD_RECONNECT_BOOT_MS`).

### Removed
- USB-stick update kit (`usb-drive/`, `pack-usb-drive.*`). It could flash stale firmware. Use PlatformIO (and `flash-recover.bat` for crash loops).

## v1.08 – v1.09 — 2026-08-01

### Changed
- **TiVo Power is no longer forwarded over BLE** (`CFG_IGNORE_TIVO_POWER_BLE=1`) — it was sleeping/waking the Shield. Use the remote's IR Power.
- **Volume/Mute are no longer forwarded over BLE** (`CFG_IGNORE_TIVO_VOLUME_BLE=1`) — they double-adjusted with IR/CEC.
- Docs: prefer wall USB power; avoid the Shield's USB port (USB serial hang → solid purple).

## v1.07 — 2026-07-13

### Fixed
- **TiVo "lost pairing" after a short drop.** A disconnect inside the 5 s confirm window now clears only **untrusted** bonds; trusted bonds reconnect instead of being wiped.

## v1.04 – v1.06

### Fixed
- **Solid yellow / solid purple boot hang** on USB hosts that enumerate the serial port but never read it (PC or Shield USB). Added `boot_early.cpp`, `Serial.setTxTimeoutMs(0)`, silenced ESP-IDF logs, and deferred serial logging until `setup()` finishes.

## v1.03 — 2026-06

### Fixed
- **Crash loop after firmware update** (`Config struct mismatch` / `ESP_ERR_NO_MEM`). NVS is erased on first boot after a firmware version change so stale Bluetooth config cannot crash the stack.

## v1.02 — 2026-06-05

### Added
- Shield link debug logging (`CFG_SHIELD_DEBUG`) and a boot reconnect window so the Shield reconnects before TiVo work starts.

## Earlier — 2026-05 / 2026-06

- Initial ESP32-C3 bridge, then migration to the **Waveshare ESP32-S3-Zero** with RGB status LED, BOOT button bond management, and WiFi removed.
- Duplicate-keypress fixes for the TiVo's dual consumer report characteristics.
- 3D-printed case, TiVo IR programming codes, flash recovery script.

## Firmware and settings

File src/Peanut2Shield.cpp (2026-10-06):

#include <Arduino.h>
#include <NimBLEDevice.h>
#include <Preferences.h>
#include <Adafruit_NeoPixel.h>
#include <nvs_flash.h>
#include <nvs.h>
#include <esp_timer.h>
#include "config.h"
#include "devlog.h"
#include "keymap.h"
#include "hid_peripheral.h"

// ---- WS2812 RGB LED (single pixel on GPIO CFG_LED_PIN) ----
// Waveshare ESP32-S3-Zero uses RGB channel order (not GRB). NEO_GRB makes
// "purple" advertising colour render as cyan on this board.
static Adafruit_NeoPixel sLed(1, CFG_LED_PIN, NEO_RGB + NEO_KHZ800);

// Set pixel to an explicit 32-bit colour (0 = off).
static inline void ledWrite(uint32_t color) {
  sLed.setPixelColor(0, color);
  sLed.show();
}

// Shorthand colour constants — keep all magic RGB values in one place.
static const uint32_t kColShield   = Adafruit_NeoPixel::Color(CFG_LED_COLOR_SHIELD);
static const uint32_t kColTivo     = Adafruit_NeoPixel::Color(CFG_LED_COLOR_TIVO);
static const uint32_t kColReady    = Adafruit_NeoPixel::Color(CFG_LED_COLOR_READY);
static const uint32_t kColReset    = Adafruit_NeoPixel::Color(CFG_LED_COLOR_RESET);
static const uint32_t kColActivity = Adafruit_NeoPixel::Color(CFG_LED_COLOR_ACTIVITY);
static const uint32_t kColBoot     = Adafruit_NeoPixel::Color(CFG_LED_COLOR_BOOT);

// ============================================================
// LED state machine
// ============================================================

enum class LedPattern : uint8_t {
  Off,
  SlowBlink,         // 500/500 ms — advertising, waiting for Shield to pair
  DoubleFlash,       // orange flash-flash … repeat — BOOT 4 s warning
  DoubleFlashShield, // purple flash-flash … repeat — BOOT 8 s Shield cleared
  ReadyOnce,         // 3 quick green flashes then → sLedAfterOnce
  ConfirmOnce,       // 3 quick flashes in sConfirmColor then → chain or BootHold
  Ready,             // steady green — both devices connected and translating
  BootBlink,         // yellow 500/500 ms — BLE stack initialising at boot
  BootHold,          // fast yellow blink — BOOT held, counting
  Activity,          // single CFG_LED_FLASH_MS pulse — button forwarded to Shield
};

struct LedStep { uint16_t ms; bool on; };

// DoubleFlash: flash, gap, flash, long-pause (repeating) — one pair per cycle
static const LedStep kDoubleFlashSteps[] = {
  { CFG_LED_DBL_FLASH_MS, true  },
  { CFG_LED_DBL_GAP_MS,   false },
  { CFG_LED_DBL_FLASH_MS, true  },
  { CFG_LED_DBL_PAUSE_MS, false },
};
static constexpr int kDoubleFlashN =
    (int)(sizeof(kDoubleFlashSteps) / sizeof(kDoubleFlashSteps[0]));

// ReadyOnce: three equally-spaced flashes (one-shot, then → sLedAfterOnce)
static const LedStep kReadyOnceSteps[] = {
  { CFG_LED_READY_FLASH_MS, true  },
  { CFG_LED_READY_GAP_MS,   false },
  { CFG_LED_READY_FLASH_MS, true  },
  { CFG_LED_READY_GAP_MS,   false },
  { CFG_LED_READY_FLASH_MS, true  },
  { CFG_LED_READY_GAP_MS,   false },
};
static constexpr int kReadyOnceN =
    (int)(sizeof(kReadyOnceSteps) / sizeof(kReadyOnceSteps[0]));

static LedPattern    sLedBase         = LedPattern::SlowBlink;
static LedPattern    sLedCurrent      = LedPattern::SlowBlink;
static LedPattern    sLedAfterOnce    = LedPattern::Ready;
static int           sLedStep         = 0;
static unsigned long sLedAt           = 0;
static uint32_t      sConfirmColor    = 0;
static LedPattern    sLedChainNext    = LedPattern::Off;
static bool          sFactoryLedSeq   = false;
static bool          sBtnLedOverride  = false;
static unsigned long sBtnAt           = 0;
static uint8_t       sBtnClicks       = 0;   // multi-press count pending commit
static bool          sBtnHeld         = false;
static bool          sBtnStableDown   = false;
static unsigned long sBtnDebounceAt   = 0;

static void ledSetBase(LedPattern p) {
  // Only skip when already showing this base (not stuck on a finished one-shot).
  if (p == sLedBase && sLedCurrent == p) return;
  sLedBase = p;
  if (sLedCurrent == LedPattern::Activity) return;
  sLedCurrent = p;
  sLedStep    = 0;
  sLedAt      = millis();
}

// Force a pattern immediately (used by boot / non-button paths).
static void ledForce(LedPattern p) {
  sLedBase = p;
  if (sLedCurrent != LedPattern::Activity) {
    sLedCurrent = p;
    sLedStep    = 0;
    sLedAt      = millis();
  }
}

// BOOT-button one-shots: change display only — never sLedBase.
// Setting base to ConfirmOnce caused infinite fast flashes and blocked syncLedState
// until another press (Activity) let sync recover the real pairing pattern.
static void ledForceButton(LedPattern p) {
  sBtnLedOverride = true;
  sLedCurrent     = p;
  sLedStep        = 0;
  sLedAt          = millis();
}

static void ledConfirmOnce(uint32_t color) {
  sConfirmColor = color;
  ledForceButton(LedPattern::ConfirmOnce);
}

static void startFactoryLedSequence() {
  sFactoryLedSeq  = true;
  sConfirmColor   = kColReset;
  sLedChainNext   = LedPattern::ReadyOnce;
  sLedAfterOnce   = LedPattern::SlowBlink;
  ledForceButton(LedPattern::ConfirmOnce);
}

// Single activity flash (highest priority). Returns to base when done.
// Only sets a request: ledTick() does the write, so the BLE callback and the
// main loop never drive the NeoPixel at the same time.
static volatile bool sLedActivityReq = false;

static void ledActivity() {
  sLedActivityReq = true;
}

// Advance the LED state machine — must be called every loop() iteration.
static void ledTick() {
  unsigned long now = millis();
  if (sLedActivityReq) {
    sLedActivityReq = false;
    sLedCurrent     = LedPattern::Activity;
    sLedAt          = now;
    ledWrite(kColActivity);
    return;
  }
  unsigned long age = now - sLedAt;

  switch (sLedCurrent) {

    case LedPattern::Off:
      ledWrite(0);
      break;

    case LedPattern::Activity:
      if (age >= CFG_LED_FLASH_MS) {
        ledWrite(0);
        sLedCurrent = sLedBase;
        sLedStep    = 0;
        sLedAt      = now;
      }
      break;

    case LedPattern::SlowBlink:
      if (sLedStep == 0) {
        ledWrite(kColShield);
        if (age >= CFG_LED_BLINK_ON_MS) { sLedStep = 1; sLedAt = now; }
      } else {
        ledWrite(0);
        if (age >= CFG_LED_BLINK_OFF_MS) { sLedStep = 0; sLedAt = now; }
      }
      break;

    case LedPattern::DoubleFlash: {
      const LedStep& s = kDoubleFlashSteps[sLedStep];
      ledWrite(s.on ? kColTivo : 0);
      if (age >= s.ms) { sLedStep = (sLedStep + 1) % kDoubleFlashN; sLedAt = now; }
      break;
    }

    case LedPattern::DoubleFlashShield: {
      const LedStep& s = kDoubleFlashSteps[sLedStep];
      ledWrite(s.on ? kColShield : 0);
      if (age >= s.ms) { sLedStep = (sLedStep + 1) % kDoubleFlashN; sLedAt = now; }
      break;
    }

    case LedPattern::ConfirmOnce: {
      const LedStep& s = kReadyOnceSteps[sLedStep];
      ledWrite(s.on ? sConfirmColor : 0);
      if (age >= s.ms) {
        sLedAt = now;
        if (++sLedStep >= kReadyOnceN) {
          sLedStep = 0;
          if (sLedChainNext != LedPattern::Off) {
            LedPattern next = sLedChainNext;
            sLedChainNext = LedPattern::Off;
            sLedCurrent   = next;
            sLedBase      = next;
          } else {
            // Back to sticky base; syncLedState (same loop) picks pairing pattern.
            sBtnLedOverride = false;
            sLedCurrent     = sLedBase;
            sLedStep        = 0;
            sLedAt          = now;
          }
        }
      }
      break;
    }

    case LedPattern::ReadyOnce: {
      const LedStep& s = kReadyOnceSteps[sLedStep];
      ledWrite(s.on ? kColReady : 0);
      if (age >= s.ms) {
        sLedAt = now;
        if (++sLedStep >= kReadyOnceN) {
          sLedBase    = sLedAfterOnce;
          sLedCurrent = sLedAfterOnce;
          sLedStep    = 0;
          if (sFactoryLedSeq) {
            sFactoryLedSeq  = false;
            sBtnLedOverride = false;
          }
        }
      }
      break;
    }

    case LedPattern::Ready:
      ledWrite(kColReady);
      break;

    case LedPattern::BootBlink:
      if (sLedStep == 0) {
        ledWrite(kColBoot);
        if (age >= CFG_LED_BLINK_ON_MS) { sLedStep = 1; sLedAt = now; }
      } else {
        ledWrite(0);
        if (age >= CFG_LED_BLINK_OFF_MS) { sLedStep = 0; sLedAt = now; }
      }
      break;

    case LedPattern::BootHold:
      if (sLedStep == 0) {
        ledWrite(kColBoot);
        if (age >= CFG_LED_BOOT_HOLD_ON_MS) { sLedStep = 1; sLedAt = now; }
      } else {
        ledWrite(0);
        if (age >= CFG_LED_BOOT_HOLD_OFF_MS) { sLedStep = 0; sLedAt = now; }
      }
      break;
  }
}

// Hardware timer keeps boot blink alive while NimBLE init blocks the loop task.
static esp_timer_handle_t sLedTimer = nullptr;

static void ledTimerCb(void* /*arg*/) { ledTick(); }

static void ledPumpStart() {
  if (sLedTimer) return;
  const esp_timer_create_args_t args = {
      .callback = &ledTimerCb,
      .arg      = nullptr,
      .dispatch_method = ESP_TIMER_TASK,
      .name     = "ledpump",
      .skip_unhandled_events = true,
  };
  if (esp_timer_create(&args, &sLedTimer) == ESP_OK) {
    esp_timer_start_periodic(sLedTimer, 10 * 1000);  // 10 ms
  }
}

static void ledPumpStop() {
  if (!sLedTimer) return;
  esp_timer_stop(sLedTimer);
  esp_timer_delete(sLedTimer);
  sLedTimer = nullptr;
}

// ============================================================
// Central (TiVo remote) state
// ============================================================

static NimBLEClient*           pClient      = nullptr;
static bool                    doConnect    = false;
static NimBLEAddress           sPendingAddr;
static bool                    sHavePendingAddr = false;
static NimBLEAddress           sBondedAddr;
static bool                    sHasBond     = false;
static bool                    sTivoBondTrusted = false;
static unsigned long           sTivoReadyAt = 0;
static unsigned long           sReconnectAt = 0;

static Preferences sTivoPrefs;

static const NimBLEUUID HID_SERVICE("1812");
static const NimBLEUUID REPORT_CHAR("2A4D");
static const NimBLEUUID REPORT_MAP_CHAR("2A4B");
static const NimBLEUUID PROTOCOL_MODE_CHAR("2A4E");

static bool sTivoConnecting = false;
static bool sTivoReady      = false;
static bool sTivoPendingSecure = false;
static bool sTivoNeedSetup  = false;
static unsigned long sTivoSecureAt = 0;
static unsigned long sTivoRetryAt = 0;
static unsigned long sShieldReadyAt = 0;
static unsigned long sBootMs = 0;
static bool sWasShieldReadyForTivo = false;
// True after Shield completes CCCD at least once since this power-on.
// Until then, do not start TiVo central — that used to stop advertising and
// leave the LED purple then solid orange with no Shield resync.
static bool sShieldEverReadyThisBoot = false;
static bool sTivoSuppressReconnect = false;
static bool sPendingForgetTiVo = false;
static unsigned long sScanLogAt = 0;
static unsigned long sTivoSoftRefreshAt = 0;   // when to run soft refresh (0 = idle)
static unsigned long sTivoLastSoftRefreshAt = 0;
static unsigned long sTivoResubAt = 0;         // next periodic re-subscribe
static int sTivoSubscribedReports = 0;
// Soft refresh only after Shield has dropped mid-session — skip cold boot /
// power-restoration first link (avoids orange double-flash stuck state).
static bool sShieldDroppedThisBoot = false;

static bool subscribeReports(NimBLERemoteService* hid);
static void printHex(const uint8_t* data, size_t len);

static void scheduleTivoRetry();
static void releaseTivoClient(NimBLEClient* client);
static void scheduleTivoSoftRefresh(const char* reason, unsigned long delayMs);
static void tivoSoftRefreshTick();
static void tivoResubscribeTick();

// Solid orange during blocking BLE work so the LED does not freeze off.
static void ledHoldForBleWork() {
  if (!sBtnLedOverride) ledWrite(kColTivo);
}

static bool tivoCentralBusy() {
  return sTivoConnecting || doConnect || sHavePendingAddr || sTivoPendingSecure ||
         sTivoNeedSetup || (pClient != nullptr && !sTivoReady);
}

// Called from onDisconnect only — link is already down; do not disconnect again.
static void releaseTivoClient(NimBLEClient* client) {
  sTivoPendingSecure = false;
  sTivoNeedSetup     = false;
  sHavePendingAddr   = false;
  if (pClient == client) pClient = nullptr;
  sTivoConnecting = false;
  sTivoReady      = false;
  hidSetTivoLinkActive(false);
  hidResumeAfterTivoCentral();
  if (client) NimBLEDevice::deleteClient(client);
}

// Drop the central client from loop / button paths (disconnect defers delete to onDisconnect).
static void cleanupTivoClient() {
  NimBLEClient* client = pClient;
  pClient = nullptr;
  sTivoPendingSecure = false;
  sTivoNeedSetup     = false;
  sHavePendingAddr   = false;
  sTivoConnecting = false;
  sTivoReady      = false;
  hidSetTivoLinkActive(false);
  hidResumeAfterTivoCentral();
  if (!client) return;
  if (client->isConnected()) client->disconnect();
  else NimBLEDevice::deleteClient(client);
}

static bool setupTivoHid(NimBLEClient* client) {
  NimBLERemoteService* hid = client->getService(HID_SERVICE);
  if (!hid) {
    DEV_LOGLN("[Central] No HID service found.");
    return false;
  }

  NimBLERemoteCharacteristic* rmap = hid->getCharacteristic(REPORT_MAP_CHAR);
  if (rmap && rmap->canRead()) {
    std::string m = rmap->readValue();
    DEV_LOGF("[Central] Report Map len=%u\r\n", m.length());
    printHex((const uint8_t*)m.data(), m.length());
  }

  NimBLERemoteCharacteristic* proto = hid->getCharacteristic(PROTOCOL_MODE_CHAR);
  if (proto && proto->canWrite()) {
    uint8_t mode = 0x01;
    proto->writeValue(&mode, 1, false);
  }

  if (!subscribeReports(hid)) {
    DEV_LOGLN("[Central] No reports subscribed.");
    return false;
  }
  if (sTivoSubscribedReports < CFG_TIVO_MIN_SUBSCRIBED_REPORTS) {
    DEV_LOGF("[Central] Only %d report CCCD(s) — expected >= %d; will soft-refresh.\r\n",
                  sTivoSubscribedReports, CFG_TIVO_MIN_SUBSCRIBED_REPORTS);
    scheduleTivoSoftRefresh("incomplete HID subscribe", 2000);
  }

  return true;
}

static void saveTiVoBond(NimBLEClient* client) {
  if (!client) return;
  sBondedAddr = client->getPeerAddress();
  sHasBond    = true;
  sTivoBondTrusted = true;
  sTivoPrefs.begin(CFG_NVS_TIVO_NS, false);
  sTivoPrefs.putString(CFG_NVS_TIVO_ADDR, sBondedAddr.toString().c_str());
  sTivoPrefs.putBool(CFG_NVS_TIVO_TRUSTED, true);
  sTivoPrefs.end();
  DEV_LOGF("[Central] TiVo bond confirmed: %s\r\n", sBondedAddr.toString().c_str());
}

static void invalidateTiVoBond(const char* reason) {
  DEV_LOGF("[Central] Clearing TiVo bond — %s\r\n", reason);
  if (sHasBond) {
    NimBLEDevice::deleteBond(sBondedAddr);
    sHasBond = false;
  }
  sTivoBondTrusted = false;
  sReconnectAt     = 0;
  sTivoPrefs.begin(CFG_NVS_TIVO_NS, false);
  if (sTivoPrefs.isKey(CFG_NVS_TIVO_ADDR))
    sTivoPrefs.remove(CFG_NVS_TIVO_ADDR);
  if (sTivoPrefs.isKey(CFG_NVS_TIVO_TRUSTED))
    sTivoPrefs.remove(CFG_NVS_TIVO_TRUSTED);
  sTivoPrefs.end();
}

static void scheduleTivoRetry() {
  sTivoRetryAt = millis() + CFG_TIVO_RETRY_MS;
}

// Shield side is "done" for TiVo work when CCCD finished, or when Shield is
// temporarily down after having linked this boot, or after the boot wait window
// (advertising stays up — see hidPauseForTivoCentral).
static bool shieldDoneForTivo() {
#if CFG_DEBUG_TIVO_ONLY
  return true;
#else
  if (hidShieldReady()) return true;
  if (!hidHasShieldBond() || hidPeripheralConnected()) return false;
  // After Shield linked once this boot, allow TiVo while Shield sleeps.
  if (sShieldEverReadyThisBoot) return true;
  // Cold boot: wait CFG_SHIELD_RECONNECT_BOOT_MS of advertising before TiVo.
  return sBootMs && (millis() - sBootMs) >= CFG_SHIELD_RECONNECT_BOOT_MS;
#endif
}

// Orange double-flash = waiting for TiVo pairing.
static bool ledWaitingForTivo() {
  if (sTivoReady && sTivoBondTrusted) return false;
#if CFG_DEBUG_TIVO_ONLY
  // DEBUG: no Shield — deep orange whenever TiVo is not fully confirmed (incl. while scanning).
  return true;
#else
  if (!hidShieldReady()) return false;
  if (!sWasShieldReadyForTivo) return false;
  if (millis() - sShieldReadyAt < CFG_TIVO_POST_SHIELD_MS) return false;
  return true;
#endif
}

// Start TiVo central scan or reconnect only after Shield pairing is complete.
static void tryStartTiVoCentral() {
  if (!shieldDoneForTivo()) return;
  if (tivoCentralBusy()) return;
  if (sTivoReady) return;
  if (sTivoRetryAt && millis() < sTivoRetryAt) return;
  // A timed reconnect is already scheduled (see onDisconnect) — let it run.
  if (sReconnectAt) return;

#if !CFG_DEBUG_TIVO_ONLY
  // Let Shield finish CCCD + initial conn-param update before central work.
  if (hidShieldReady()) {
    sShieldEverReadyThisBoot = true;
    if (!sWasShieldReadyForTivo) {
      sWasShieldReadyForTivo = true;
      sShieldReadyAt         = millis();
    }
    if (millis() - sShieldReadyAt < CFG_TIVO_POST_SHIELD_MS) return;
  } else {
    sWasShieldReadyForTivo = false;
  }
#endif

  if (sHasBond && sTivoBondTrusted) {
    if (!doConnect) {
#if CFG_DEBUG_TIVO_ONLY
      DEV_LOGLN("[Central] DEBUG — reconnecting to trusted TiVo bond...");
#else
      DEV_LOGLN("[Central] Reconnecting to trusted TiVo bond...");
#endif
      doConnect = true;
    }
    return;
  }

  if (sHasBond && !sTivoBondTrusted) {
    static bool sWarnedUntrusted = false;
    if (!sWarnedUntrusted) {
      sWarnedUntrusted = true;
      DEV_LOGLN("[Central] Unconfirmed TiVo addr — reset remote, any btn for pairing.");
    }
  }

  NimBLEScan* scan = NimBLEDevice::getScan();
  if (scan && !scan->isScanning()) {
#if CFG_DEBUG_TIVO_ONLY
    DEV_LOGLN("[Central] DEBUG — scanning for TiVo (pairing mode on remote).");
#else
    DEV_LOGLN("[Central] Shield ready — scanning for TiVo (pairing mode on remote).");
#endif
    DEV_LOGLN("[Central] Remote: Power+TiVo → Vol− x3 → TiVo → any button (pairing mode).");
    sScanLogAt = millis();
    scan->start(0, nullptr, false);
  }
}

// ============================================================
// LED sync — set background pattern from BLE state automatically.
// Skips if a button-driven special pattern is active.
// ============================================================

static void syncLedState() {
  // BOOT confirmation / factory chain take priority over BLE state.
  if (sBtnLedOverride) return;
  if (sLedCurrent == LedPattern::ReadyOnce)  return;
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
void loop() {
  // ---- LED and button (non-blocking) ----
  buttonTick();
  serialCmdTick();
  ledTick();

  if (sPendingForgetTiVo) {
    sPendingForgetTiVo = false;
    forgetTiVo();
  }

  {
    NimBLEScan* scan = NimBLEDevice::getScan();
    if (scan && scan->isScanning() && shieldDoneForTivo() && !sTivoReady &&
        !tivoCentralBusy() && (millis() - sScanLogAt >= 15000)) {
      sScanLogAt = millis();
      DEV_LOGLN("[Central] Still scanning — put remote in pairing mode.");
      DEV_LOGLN("[Central]   Power+TiVo → Vol− x3 → TiVo → any button.");
    }
  }

  syncLedState();
  tryStartTiVoCentral();
  tivoCentralTick();
  tivoBondConfirmTick();

  // ---- Shield CCCD edge — schedule fast BLE params ----
  {
    bool isReady = hidShieldReady();
    if (isReady && !sWasShieldReady) {
      sShieldEverReadyThisBoot = true;
      sShieldParamsAt = millis() + CFG_SHIELD_FAST_PARAMS_DELAY_MS;
      DEV_LOGLN("[HID] Shield CCCD confirmed — fast params in 1 s.");
      // Mid-session re-ready only — cold boot / power restore must not soft-refresh.
      if (sShieldDroppedThisBoot) {
        scheduleTivoSoftRefresh("Shield re-ready after drop",
                                CFG_TIVO_SOFT_REFRESH_AFTER_SHIELD_MS);
      }
    }
    if (!isReady && sWasShieldReady) {
      sShieldDroppedThisBoot = true;
#if CFG_SHIELD_DEBUG
      DEV_LOGF("[HID-DBG] Shield left ready (state=%s)\r\n", hidGetShieldState());
#endif
      // Don't soft-refresh on the drop itself — wait until Shield is back, then refresh.
    }
    sWasShieldReady = isReady;
  }

#if CFG_SHIELD_DEBUG
  hidShieldDebugTick(pClient != nullptr && pClient->isConnected(),
                       sTivoReady, tivoCentralBusy());
#endif

  if (sShieldParamsAt && millis() >= sShieldParamsAt) {
    sShieldParamsAt = 0;
    hidRequestFastParams();
    if (sShieldDroppedThisBoot) {
      scheduleTivoSoftRefresh("after Shield fast params (post-drop)",
                              CFG_TIVO_SOFT_REFRESH_AFTER_SHIELD_MS);
    }
  }

  // Heal: BLE link up + trusted bond but ready flag cleared (power-race leftover).
  if (!sTivoReady && sTivoBondTrusted && pClient && pClient->isConnected() &&
      !sTivoConnecting && !sTivoPendingSecure && !sTivoNeedSetup) {
    DEV_LOGLN("[Central] Heal — TiVo connected/trusted but not ready; re-running HID setup.");
    sTivoNeedSetup = true;
  }

  tivoResubscribeTick();
  tivoSoftRefreshTick();

  // ---- Timed reconnect after TiVo disconnect ----
  if (sReconnectAt && millis() >= sReconnectAt) {
    sReconnectAt = 0;
    if (!sTivoReady && !tivoCentralBusy()) doConnect = true;
  }

  if (doConnect) {
    doConnect = false;

    NimBLEAddress addr;
    bool hasAddr = false;

    if (sHasBond) {
      addr    = sBondedAddr;
      hasAddr = true;
    } else if (sHavePendingAddr) {
      addr    = sPendingAddr;
      hasAddr = true;
      sHavePendingAddr = false;
    }

    if (hasAddr) {
      if (!tivoStartConnect(addr)) {
        DEV_LOGLN("[Central] Connect failed — retrying shortly.");
        tryStartTiVoCentral();
      }
    }
  }

  if (sTivoRetryAt && millis() >= sTivoRetryAt) {
    sTivoRetryAt = 0;
    tryStartTiVoCentral();
  }

  delay(1);
}

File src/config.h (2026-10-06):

#pragma once

// =============================================================================
// config.h - All compile-time constants for TiVo BLE HID Translator
// Edit this file to customise behaviour without touching any other source file.
// =============================================================================

// -----------------------------------------------------------------------------
// BLE device identity
// -----------------------------------------------------------------------------

// Name broadcast by the ESP32 over BLE (visible during Shield pairing scan)
#define CFG_BLE_DEVICE_NAME  "Peanut2Shield"

// Firmware version (serial banner, README, firmware/ image names)
#define CFG_FIRMWARE_VERSION  "v1.21"

// BLE appearance value advertised to Android TV.
// 0x0180 = Generic Remote Control - avoids the PIN-entry flow triggered by
// the Keyboard appearance (0x03C1) on Android TV.
#define CFG_BLE_APPEARANCE   0x0180

// -----------------------------------------------------------------------------
// BLE advertising intervals (units of 0.625 ms)
// Fast intervals improve discoverability during pairing.
// -----------------------------------------------------------------------------

#define CFG_ADV_MIN_INTERVAL  32   // 32 x 0.625 ms = 20 ms
#define CFG_ADV_MAX_INTERVAL  64   // 64 x 0.625 ms = 40 ms

// Slow advertising while TiVo central is still connected and Shield is down.
// Fast 20–40 ms re-advertise after Shield drop starves the TiVo link (dual-role).
#define CFG_ADV_SLOW_MIN_INTERVAL  160  // 160 x 0.625 ms = 100 ms
#define CFG_ADV_SLOW_MAX_INTERVAL  480  // 480 x 0.625 ms = 300 ms

// -----------------------------------------------------------------------------
// BLE connection parameters
// Applied on both the Central (TiVo) and Peripheral (Shield) links.
// Interval units = 1.25 ms; timeout units = 10 ms.
// -----------------------------------------------------------------------------

#define CFG_CONN_MIN_INTERVAL  6   //  6 x 1.25 ms =  7.5 ms
#define CFG_CONN_MAX_INTERVAL  12  // 12 x 1.25 ms = 15.0 ms
#define CFG_CONN_LATENCY       0   // peripheral may not skip any events
#define CFG_CONN_TIMEOUT       51  // 51 x 10 ms = 510 ms — Shield peripheral link

// TiVo central link: longer supervision timeout (510 ms is too short — remote drops).
#define CFG_TIVO_CONN_MIN_INTERVAL  12  // 15 ms
#define CFG_TIVO_CONN_MAX_INTERVAL    24  // 30 ms
#define CFG_TIVO_CONN_LATENCY          0
#define CFG_TIVO_CONN_TIMEOUT        400  // 400 x 10 ms = 4 s

// Seconds before a central connection attempt is abandoned
#define CFG_CONNECT_TIMEOUT_S  10

// -----------------------------------------------------------------------------
// BLE scan parameters (Central side - scanning for the TiVo remote)
// Low duty cycle (~15%) leaves airtime for the peripheral advertising.
// -----------------------------------------------------------------------------

#define CFG_SCAN_INTERVAL  200  // 200 x 0.625 ms = 125 ms scan period
#define CFG_SCAN_WINDOW     30  //  30 x 0.625 ms = 18.75 ms active per period

// -----------------------------------------------------------------------------
// Timing delays (milliseconds)
// -----------------------------------------------------------------------------

// Duration of the forced key-release pulse sent after a keyboard-translated
// keydown. Prevents the Shield from auto-repeating F-key / ESC mappings.
#define CFG_KB_PULSE_MS  30

// How long the activity LED stays lit after each forwarded keydown event.
#define CFG_LED_FLASH_MS  80

// Delay after TiVo disconnects before attempting to reconnect.
#define CFG_TIVO_RECONNECT_MS  3000

// Delay before retrying TiVo connect/scan after a failed attempt.
#define CFG_TIVO_RETRY_MS  2000

// Pause after BLE connect before calling secureConnection (lets link stabilize).
#define CFG_TIVO_SECURE_DELAY_MS  400

// Connection must stay up this long before a *new* TiVo bond is saved / trusted.
// Already-trusted bonds are never cleared by a short drop (reconnect instead).
#define CFG_TIVO_BOND_MIN_UP_MS  5000

// Wait after Shield is ready before starting TiVo scan/connect (lets CCCD + conn params settle).
#define CFG_TIVO_POST_SHIELD_MS  1500

// After reboot, wait this long for the Shield before allowing TiVo central work
// *without* a live Shield link (runtime reconnect while Shield is asleep).
// Cold boot still prefers a real Shield link first (see sShieldEverReadyThisBoot).
#define CFG_SHIELD_RECONNECT_BOOT_MS  30000

// Delay after the Shield's first CCCD write before requesting fast BLE params.
// Gives the BLE stack time to finish service discovery before changing intervals.
#define CFG_SHIELD_FAST_PARAMS_DELAY_MS  1000
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

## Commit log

2026-05-28 Initial commit: TiVo to Shield BLE HID Translator. ESP32-C3 firmware bridging a TiVo Stream 4K remote to Nvidia Shield TV over BLE with dual Central/Peripheral roles, NVS keymap, and WiFi web admin p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
2026-05-28 Add live device status panel with BLE state machine and polling
2026-05-28 Fix JS syntax error in updDst (double ternary broke all tab switching)
2026-05-28 Restart advertising after TX power change to restore Shield connection
2026-05-28 Fix pairing visibility: rebuild advertising PDU with fast 20-40ms intervals on forget/power change
2026-05-28 Increase bounce guards: kAllZeroGuardMs 50→80, kBounceMsGuard 150→300
2026-06-02 Peanut2Shield: migrate to ESP32-S3-Zero, add LED/button, remove WiFi
    - Rename project to Peanut2Shield; ble_sniffer.cpp -> Peanut2Shield.cpp
    - Migrate target board to Waveshare ESP32-S3-Zero (4 MB flash)
    - Remove all WiFi/AP/web-config code (web_config.cpp/h deleted)
    - Add src/config.h: all compile-time constants centralised
    - Drive WS2812 RGB LED via Adafruit NeoPixel with per-state colours:
    yellow=boot, purple=advertising, orange=waiting for TiVo,
    green=ready, white=activity, red=factory-reset hold
    - Non-blocking LED state machine driven by ledTick() in loop()
    - Boot button (GPIO 0): 3s forget TiVo, 6s forget Shield, 10s factory reset
    - Split bounce guard: nav keys bypass guard, ac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
    [Peanut2Shield.cpp, config.h]
2026-06-02 stl files
    [base.stl, led.stl, top.stl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]
2026-06-02 fixed boot color and license
    [Peanut2Shield.cpp, config.h]
2026-07-14 Keep trusted TiVo bonds across short reconnect drops.
    v1.07 only clears an unconfirmed bond in the 5s window; already-paired remotes reconnect instead of losing pairing mid-use.
    [Peanut2Shield.cpp, config.h]
2026-09-10 power outage fix
